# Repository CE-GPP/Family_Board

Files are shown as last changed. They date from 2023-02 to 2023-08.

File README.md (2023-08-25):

# by Team 4 for CASA0021

- Leo Liu : ucfniup@ucl.ac.uk

- Sophia Chong : sophia.chong.19@ucl.ac.uk
- Xiaoya Nie : ucfnnie@ucl.ac.uk

We built the family board project. If you have any questions, please contact us.

# Family Board

Project introduction:

Family board is a device that can allow family members to upload and share their location with family members. It has a physical device and its digital twin on the Android Unity Mobile Application. All the location information is self-reported. It does not have privacy issues (like personal location tracking). This device has a warm, home-like appearance.

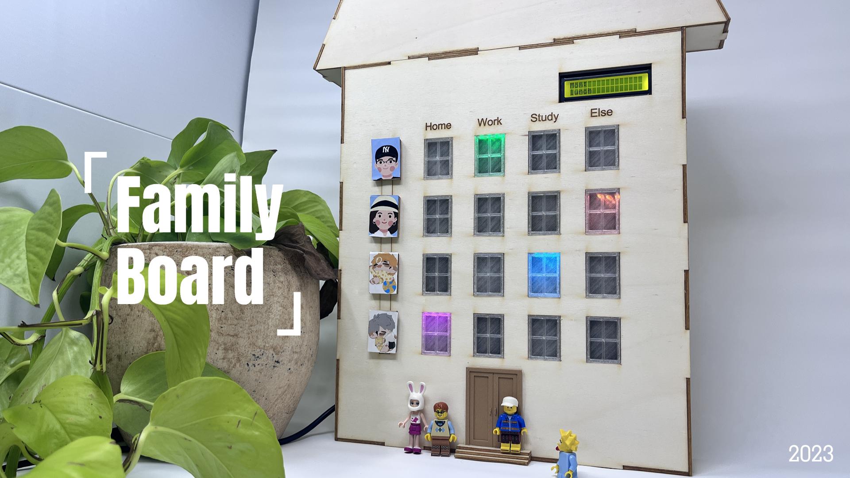
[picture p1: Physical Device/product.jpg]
 - 

To use the physical device, user just need to tap their unique PFID tag on the "door", the window light on the device will change.
User can also change location in app. When they are at other location, they can input message in the pannel. The physical device will show the message on the LCD screen.

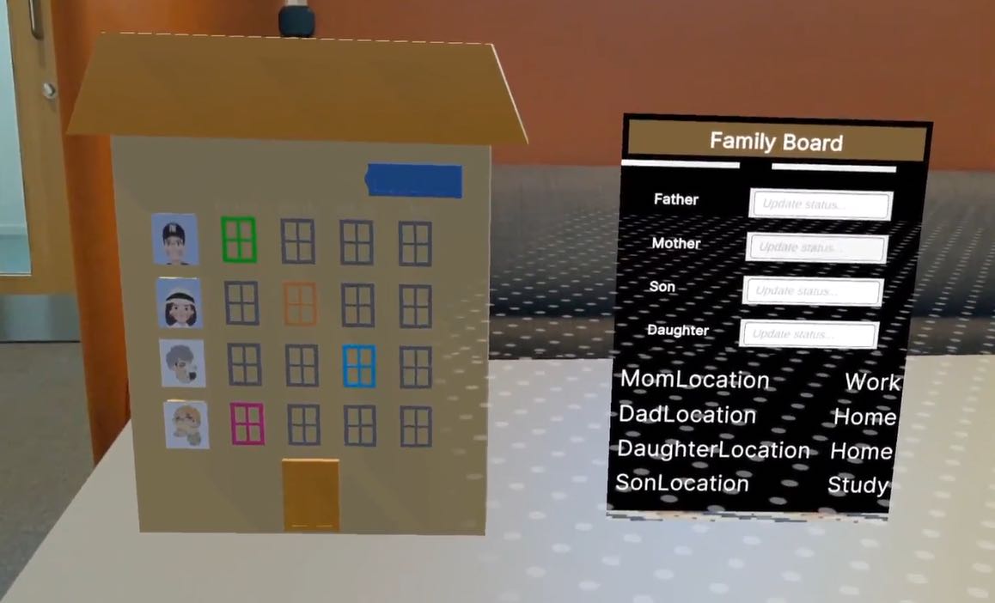
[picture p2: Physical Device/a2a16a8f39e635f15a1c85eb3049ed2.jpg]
 - 

# Getting Started

## Physical Device:

### 1. Hardware required:

The hardware required for the project are:

1). Adafruit Feather HUZZAH ESP8266 

2). MRCF522 RFID module

3). WS2812b led strip: to make the led strip fit with the family board, it need to be cut in to 4 pieces, and solder with cable to rebuild the circuit connection.

4). LCD (I2C)

The function of the hardware can be found below:

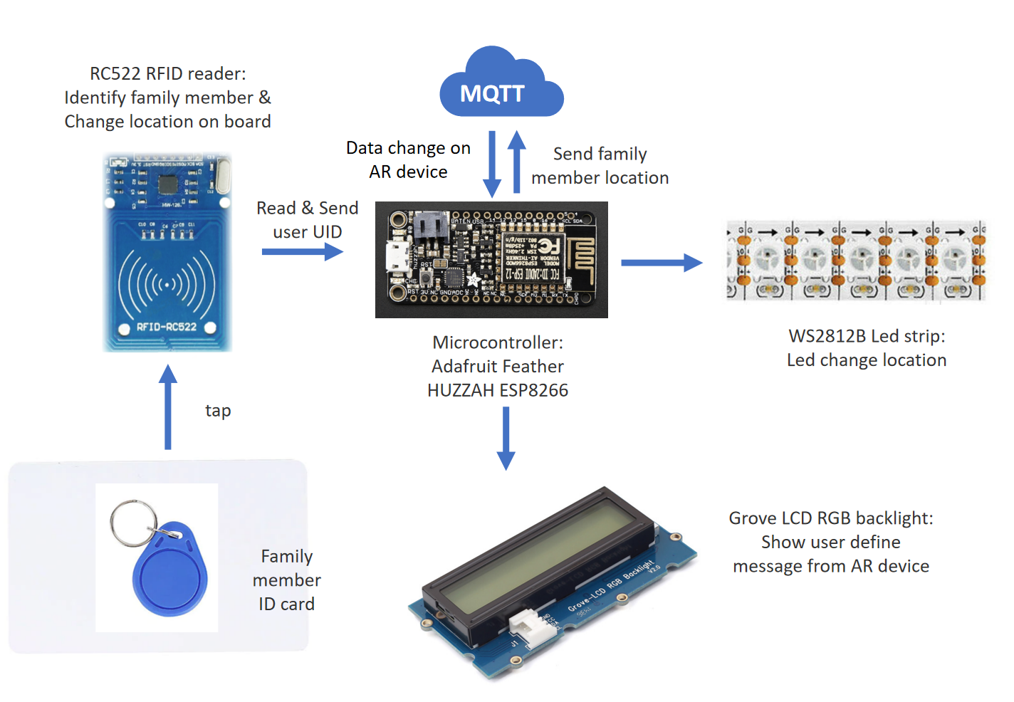
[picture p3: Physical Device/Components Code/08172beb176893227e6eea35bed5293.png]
 - 
 
### 2. Hardware code:

The code for the hardware is in the Physical device folder: CardLCD.ino.
The platform used for the project is Arduino IDE. Please download the code and upload it to the microcontroller.
The circuit connection for the RFID module can also be found in the code.

## 3. Physical Model and Assembly
You will need:
1. 3mm plywood
2. All the leftover plywood scraps from laser cutting
3. Access to a laser cutter
4. Access to a 3D printer
5. Access to a printer
6. Paper
7. Portraits of 4 family members
8. Transparent PLA filament
9. Wood PLA filament
10. Wood glue
11. Tape
12. Multipurpose adhesive
13. Fine grain sandpaper
14. 1 piece of black paper
15. A magnetic sheet
16. Scissors
17. Ruler
18. Cable ties

## 3.1 3D printing
Download the files in the [3D printed components folder](https://github.com/CE-GPP/Family_Board/tree/main/Physical%20Device/3D%20printed%20components) in the Physical Device folder. 
Upload both gcode files to the SD card of a 3D printer, and print the familyBoardDoor with 0.2mm wood PLA filament.
Next, print the twoFamilyBoardWindows with 0.2mm transparent PLA filament, and **repeat this 8 times** to print all 16 windows you need. 
Next, print the familyBoardLCDScreenHolder with 0.2mm PLA filament of your choice.

## 3.2 Laser cutting
Download both files in the [Laser cut template folder](https://github.com/CE-GPP/Family_Board/tree/main/Physical%20Device/Laser%20cut%20template) in the Physical Device folder.

### 3.2.1 Laser cutting the family board face
After opening the familyBoardFace file and exporting it to the laser cutter, set the **location labels** and **spaces for the magnetic family portraits**, which are the **first columnn of rectangles from the left** to **engrave** instead of **cut**. All other lines can be set to **cut**. 
After making this change, it can be laser cut onto 3mm plywood.

### 3.2.2 Laser cutting the family board roof
After opening the familyBoardRoof file and exporting it to the laser cutter, ensure that all its lines are set to **cut**. It can then be laser cut onto 3mm plywood.

## 3.3 Assembling the family board
After you have laser cut the family board face, **keep the leftover plywood scraps** as you need them for later.

### 3.3.1 Assembling the family board face
Assemble the exterior faces of the board with wood glue one by one, and tape each of glued edges together for a secure finish. In the process, ensure that all the components are orientated correctly, and check that the slots at the side of the board are close to the board's front instead of the board's back. 

Next, glue the two walls without finger joints to the top and bottom of the board's interior. Ensure that it is glued as tightly as possible, as this is going to form the rail for the sliding face.

Glue the top of the rails to the back of the top and bottom faces of the board, and glue the grip rail to the sliding face.

Very carefully slot the sliding face of the board into the rail created for it, with the raised edge of the grip rail facing outwards, and check whether it is able to slide in smoothly or not.If not, then remove the debris inside the rail or sand down the wood edges for smoother motion.


Tape or glue the piece of black paper to the back of sliding face, in the area that will be behind the windows when the board is closed. This will prevent excessive light reflection between each window from the LED strip.


Glue the support beams into the sides of the board, with the side with the hole closer to the end of the beam on the left side (the side of the LCD screen) of the board.

Glue the stair pieces to each other, then glue it underneath the hole for the door in the front of the board, so that the hole for the door is positioned above the middle of the stairs, about 10mm away from each end.

After following these steps, you should have a completely assembled the laser cut components of your family board face. Leave the board to dry for at least 2 hours.
 
### 3.3.2 Assembling the family board roof
Assemble each face of the roof with wood glue one by one, and tape each of the glued edges together for a secure finish. It should look like this:


Leave the roof to dry for at least 2 hours.

Then you can glue the longer base of the roof to the top of the family board, leaving about 35mm of overhang on each side.


## 3.4 Adding 3D printed and electronic components

### 3.4.1 Adding the 3D printed components
Slot each of the 3D printed windows into the 4 rows of rectangular holes on the board. In this process, you will have to slightly sand down the edges of each window and the holes in the board to make them fit snugly without adhesive. 

Next, glue the 3D printed door to the front of the board on top of the stairs with multipurpose adhesive, covering the hole.

The board should now look like this:


Slot the LCD screen into the 3D printed LCD screen holder, and position it on top of the top inner support beam so the LCD screen is aligned with and visible from the hole cut for it in the front of the board. To do so, you may need to place a scrap piece of plywood underneath the LCD screen holder to prop it up so the screen can be fully visible through the hole. 


Then take out the LCD screen to wire it, and glue the LCD screen holder into the suitable position with multipurpose adhesive.

### 3.4.2 Adding electronic components
Wire the electronic components of the device. 

Thread the LED strip through each of the support beams and position them on underside of each one. To ensure the correct positioning of each LED pixel in accordance with our code, each of the 4 LED strips should always be placed from **right(side close to the family portraits magnets)** to **left (side close to the LCD screen)**. The spacing should be accurate if you position **the first 4 LED pixels** on each separate LED strip **behind the window the far right (side close to the family portait magnets)** in each row. Afterwards, peel the sticker off the LED strip and stick them in the correct position, and further secure it with cable ties.


Slot the wired LCD screen into the now-secured LCD screen holder. 


Position the RFID reader horizontally in the space behind the 3D printed door. 
Place 2 leftover plywood scraps perpendicular to each other and glue them to the bottom of the board near the corner of the RFID reader to secure it in place behind the door.  


### 3.4.3 Adding the family portrait magnets
To create the family portrait magnets, print the portraits of four of your family members on paper around 36mm tall and 26mm wide and cut them out.
Cut 8 rectangles of that same length and width (36mm x 26mm) out of your magnetic sheet. Glue 4 of them in the engraved rectangles on the face of the family board with multipurpose adhesive to make the magnetic surface to attach the family portrait magnets to. 
Glue your printed family portraits to the remaining 4 magnetic sheets, and stick them onto the 4 magnetic surfaces of the board.

After following these steps, the physical family board should be ready for use!



## Virtual Device:

### 1. Download The Virtual Device Android APP from Unity

1. Head over to the [Family Board Virtual Device folder](https://github.com/CE-GPP/Family_Board/tree/main/Unity/Family%20Board%20Virtual%20Device) and open the folder as a new project in Unity. Before you begin, make sure that your project is set up in Unity 2021.3.13f1. The Mobile application for Family Board only supports the Android platform.

2. In Unity, open the Prefab folder and double-click the "Final model" file to open it. In the Hierarchy window on the left, click the UI layer under "Final model" once. Then, enter your MQTT user name and password under "Mqtt Receiver List (Script)" in the Inspector window on the right. Feel free to change the MQTT broker address and use your own MQTT server instead of the CE MQTT server. Save your project to prepare for building the app in the next step.

3. From the top menu bar, select File and go to Build Settings. Select Android from the right platform lists and click Build and Run. Then, save the project in the desired location and make sure the Android mobile device is connected to Unity through a USB cable. Do not disconnect the mobile device until the Unity app automatically starts on the device.

### 2. The Virtual Device Android APP

The goal of the Android app developed using Unity is to allow users to check or manipulate their family boards remotely through their mobile devices. The app contains a digital twin of the physical device and a user interface panel.

The virtual device has the same functions and appearance as the physical device, and the model was imported into Unity from Fusion 360 directly. Both physical and virtual devices are connected through MQTT. However, the LCD is not responsive on the virtual device because the UI panel beside it can display more information in a clear and organized way. The virtual device is interactable since users can change their status by clicking on the windows. We kept the buttons transparent for better user experiences. 

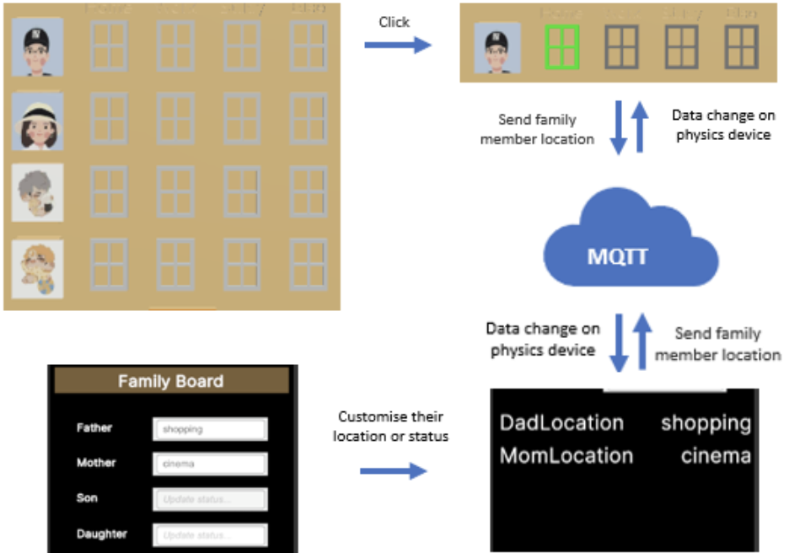
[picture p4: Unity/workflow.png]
- 
- AR application workflow.

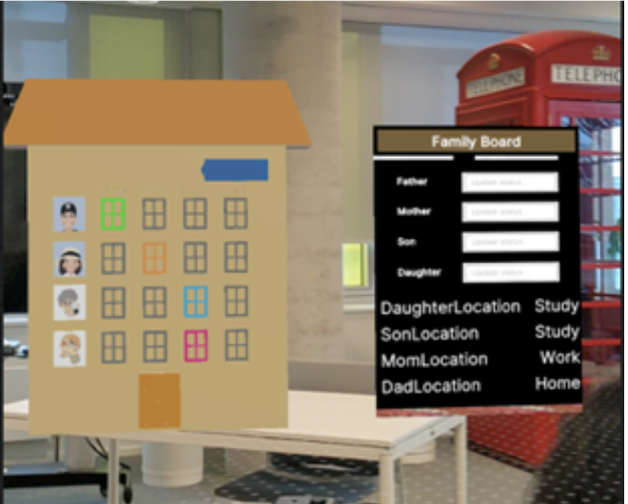
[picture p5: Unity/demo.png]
- 
- The final version of the Virtual device and the Android app.

# Contributing

This project welcomes contributions and suggestions.  Most contributions require you to agree to a
Contributor License Agreement (CLA) declaring that you have the right to, and actually do, grant us
the rights to use your contribution. For details, visit https://cla.microsoft.com.

When you submit a pull request, a CLA-bot will automatically determine whether you need to provide
a CLA and decorate the PR appropriately (e.g., label, comment). Simply follow the instructions
provided by the bot. You will only need to do this once across all repos using our CLA.

This project has adopted the [Microsoft Open Source Code of Conduct](https://opensource.microsoft.com/codeofconduct/).
For more information see the [Code of Conduct FAQ](https://opensource.microsoft.com/codeofconduct/faq/) or
contact [opencode@microsoft.com](mailto:opencode@microsoft.com) with any additional questions or comments.

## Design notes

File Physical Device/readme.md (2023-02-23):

## Physical device

### The design and code for physical device

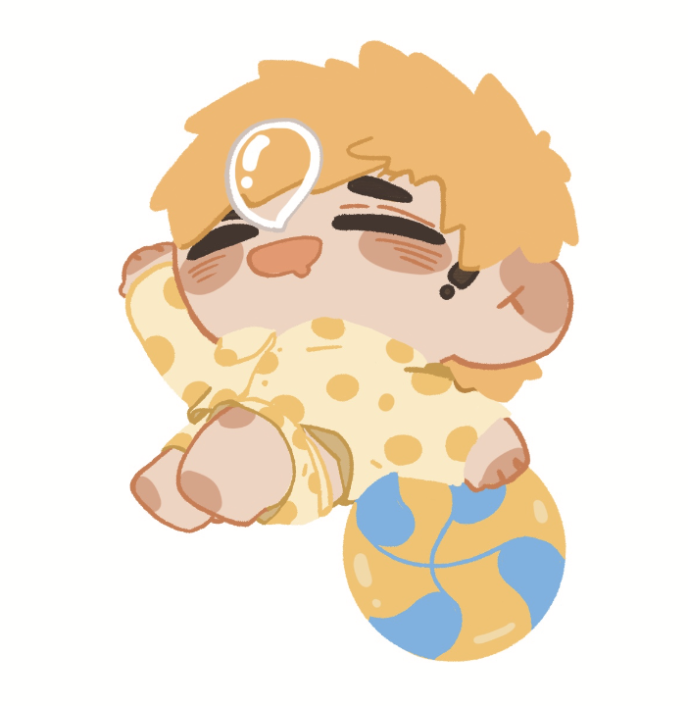
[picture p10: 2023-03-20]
Unity/Family Board Virtual Device/Assets/Prefab/Daughter.jpg

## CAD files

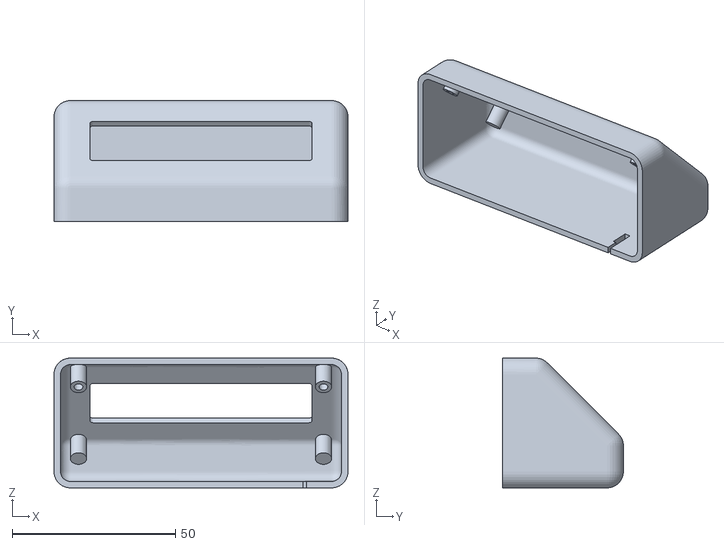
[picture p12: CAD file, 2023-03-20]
Fusion 360/lcd_housing.STL
90.0 x 37.0 x 39.7

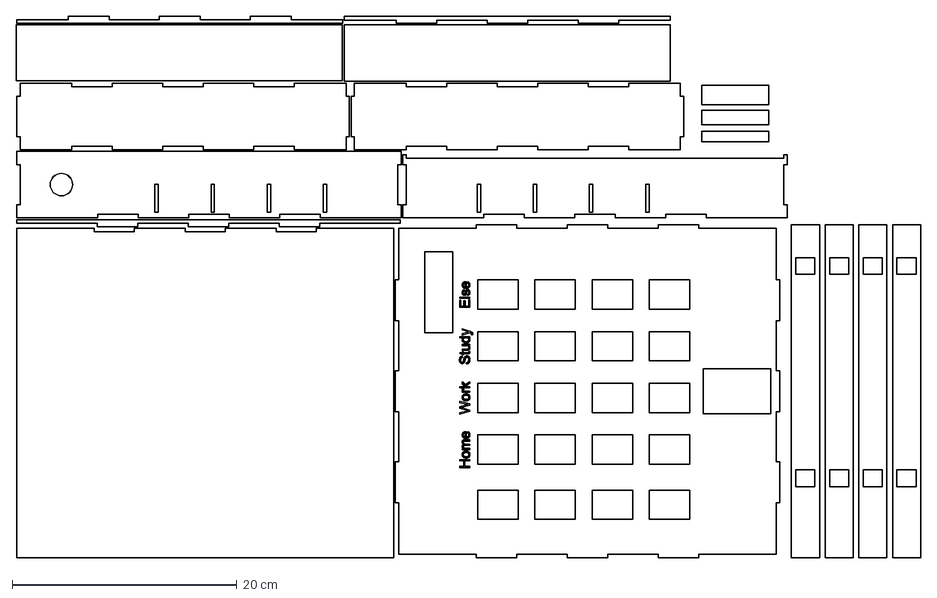
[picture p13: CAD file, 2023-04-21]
Physical Device/Laser cut template/familyBoardFace.dxf
80.5 x 48.2 cm

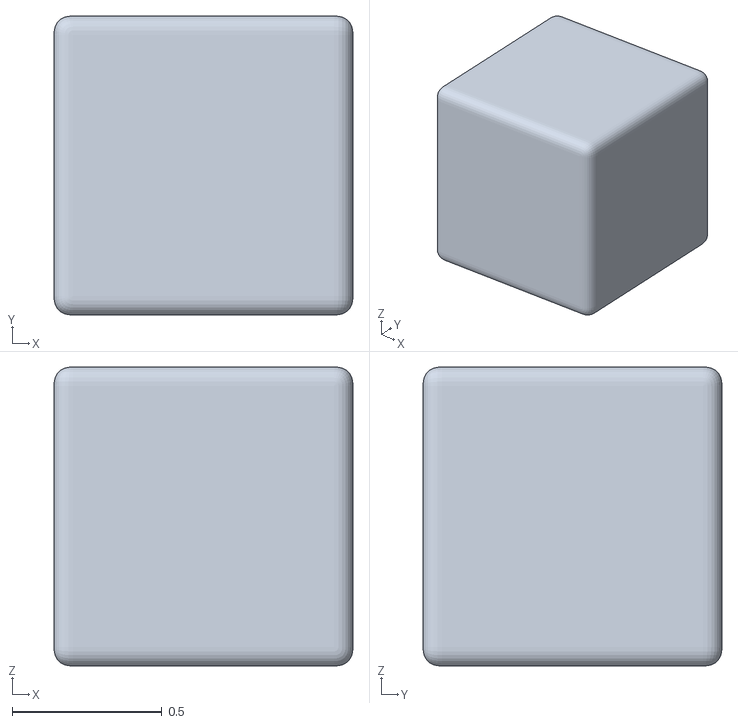
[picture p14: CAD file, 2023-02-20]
Unity/Family Board Virtual Device/Assets/Plugins/CW/LeanCommon/Examples/Meshes/RoundedCube.obj
1.00 x 1.00 x 1.00

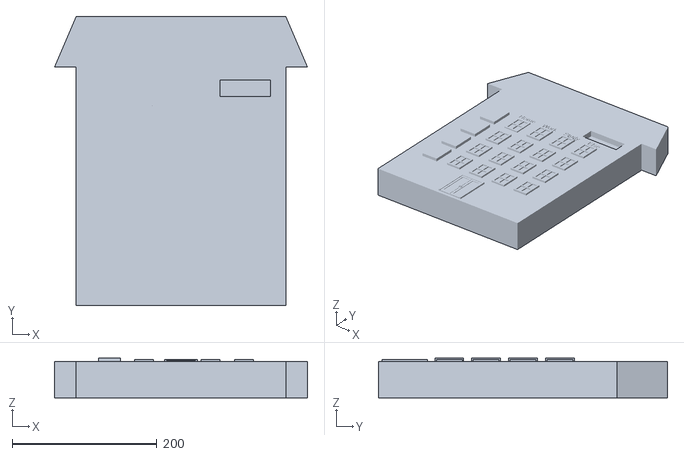
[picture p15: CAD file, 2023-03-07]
Unity/Family Board Virtual Device/Assets/Prefab/familyBoardSTL.stl
350.0 x 400.0 x 55.0

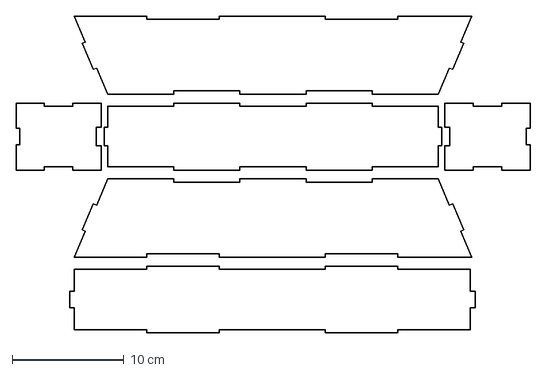
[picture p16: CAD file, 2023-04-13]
Physical Device/Laser cut template/familyBoardRoof.dxf
46.1 x 28.4 cm

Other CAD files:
Unity/familyBoardOBJ.obj
Fusion 360/boardDoor.f3d
Fusion 360/boardRoof.f3d
Fusion 360/boardWindow.f3d
Fusion 360/familyBoardTemplate.f3d
Fusion 360/status_board_vertical_v9.f3d
Unity/Family Board Virtual Device/Assets/Prefab/s_board_vertical_v9_v159_v15.f3z

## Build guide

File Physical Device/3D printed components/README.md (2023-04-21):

3D printed components of our familly board

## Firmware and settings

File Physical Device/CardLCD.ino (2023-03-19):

/*
 * Family Board - Physical device 
 *
 * Uses MIFARE RFID card using RFID-RC522 reader
 * Uses MFRC522 - Library
 * -----------------------------------------------------------------------------------------
 *             MFRC522      Arduino      
 *             Reader/PCD   Feather Huzzah 
 * Signal      Pin          Pin          
 * -----------------------------------------------------------------------------------------
 * RST/Reset   RST          0           
 * SPI SS      SDA(SS)      15            
 * SPI MOSI    MOSI         13
 * SPI MISO    MISO         12
 * SPI SCK     SCK          14
*/

//library used in the project, for LCD RFID Reader, Wifi MQTT
#include <SPI.h>
#include <MFRC522.h>
#include <ESP8266WiFi.h>
#include <ESP8266WebServer.h>
#include <ezTime.h>
#include <PubSubClient.h>
#include <FastLED.h>
#include <Wire.h>
#include <LiquidCrystal_I2C.h>

//pin define
#define LED_PIN     16
#define NUM_LEDS    96

//LED strip brightness
int brightness = 50; 

CRGB leds[NUM_LEDS];
 
#define SS_PIN 15
#define RST_PIN 0

MFRC522 rfid(SS_PIN, RST_PIN); 
 
// initialize array to store NUID that has been read
byte nuidPICC[4];
const int numOfCards = 4;//the nuber of cards. this can change as you want
byte cards[numOfCards][4] = {{0xC3, 0x08, 0x30, 0x95},{0x73, 0x25, 0x3F, 0x92},{0x73, 0x25, 0x3F, 0x93},{0x73, 0x25, 0x3F, 0x94}}; // array of UIDs of rfid cards
int n = 0;//n is for the total number of family members
//j is for to detect the card is valid or not
int numCard[numOfCards]; //this array content the details of cards that already detect or not .
String names[numOfCards] = {"Dad","Mom","Daughter","Son"};//each family member
//1-Home,2-Study,3-Work,4-Else;
int fLocations[numOfCards] = {1,1,1,1};//family member locations


// Wifi and MQTT
#include "arduino_secrets.h" 

//sensitive data saved in arduino secret file
const char* ssid     = SECRET_SSID;
const char* password = SECRET_PASS;
const char* mqttuser = SECRET_MQTTUSER;
const char* mqttpass = SECRET_MQTTPASS;

//MQTT and WiFi connection
ESP8266WebServer server(80);
const char* mqtt_server = "mqtt.cetools.org";
WiFiClient espClient;
PubSubClient client(espClient);
long lastMsg = 0;
char msg[50];
int value = 0;

// Date and time
Timezone GB;

//LCD Display
int totalColumns = 16;
int totalRows = 2;
//I2C pins declaration for 1602A with I2C module
LiquidCrystal_I2C lcd(0x27, totalColumns, totalRows);

void setup() { 
  Serial.begin(9600);
  SPI.begin(); // initialize SPI
  rfid.PCD_Init(); // initialize MFRC522 

    // run initialisation functions
  startWifi();
  syncDate();

  FastLED.addLeds<WS2812, LED_PIN, GRB>(leds, NUM_LEDS);
  FastLED.setBrightness(brightness);

  // start MQTT server
  client.setServer(mqtt_server, 1884);
  client.setCallback(callback);

  // set up the LCD's number of columns and rows:
   lcd.init();
   lcd.backlight();  // use to turn on and turn off LCD back light

}
 
void loop() {
  //verify MQTT connection
  if (!client.connected()) {
    reconnect();
  }
  client.loop();
 
  // find card
  if ( ! rfid.PICC_IsNewCardPresent())
    return;
 
  // verify if NUID is readable
  if ( ! rfid.PICC_ReadCardSerial())
    return;
  int j = -1;
  MFRC522::PICC_Type piccType = rfid.PICC_GetType(rfid.uid.sak);
 
  // Check whether the card type is MIFARE
  if (piccType != MFRC522::PICC_TYPE_MIFARE_MINI &&  
    piccType != MFRC522::PICC_TYPE_MIFARE_1K &&
    piccType != MFRC522::PICC_TYPE_MIFARE_4K) {
    Serial.println("Type not support");
    return;
  }
  
  // Save the NUID to the nuidPICC array
  for (byte i = 0; i < 4; i++) {
    nuidPICC[i] = rfid.uid.uidByte[i];
  }   

  for (int i = 0; i < numOfCards; i++) {
    if (nuidPICC[0] == cards[i][0] && nuidPICC[1] == cards[i][1] && nuidPICC[2] == cards[i][2] && nuidPICC[3] == cards[i][3]) {
      j = i;
    }
  }
  if(j == -1) {//check the card validity
    invalid();
  }
  else {
    //send data to display and save
    logCardData(names[j], fLocations[j], j);
    sendMQTT();
  }

  
  // set IC card placed in the reading area enters hibernation state, no longer read the card repeatedly
  rfid.PICC_HaltA();
 
  // Stop reading the card module code
  rfid.PCD_StopCrypto1();

}
//function for invalid information
void invalid(){
  Serial.println("Invalid Card.");
  lcd.clear();
  // Print a message to the LCD.
  lcd.setCursor(0, 0);
  lcd.print("Card not defined");
}

//function for Change family member location
void logCardData(String name, long fLocation, int j){
  //change card location
  fLocations[j] = fLocations[j] + 1;
  if (fLocations[j]==5)
  {
    fLocations[j]=1;
  }
  numCard[j] = 1;//put 1 in the numCard array : numCard[j]={1,1} to let the arduino know if the card was detecting

  //display details to the console (serial monitor)
  Serial.print("Family member: ");
  Serial.println(name); //print name of family member
  Serial.print("Location: ");
  Serial.println(fLocation); //print location of member
  Serial.println();
  showLED();
  FastLED.show();

}

//function for change led strip light
void showLED(){
  Serial.println("change light");
  FastLED.clearData();
  //dad location
  switch (fLocations[0]) {
    case 1:  // home
    for (int i = 72; i <= 75; i++) {
    leds[i] = CRGB (0, 0, 255);
    }
      break;
    case 2:  // study
    for (int i = 79; i <= 82; i++) {
    leds[i] = CRGB ( 0, 0, 255);
    }
      break;
    case 3:  // work
    for (int i = 86; i <= 89; i++) {
    leds[i] = CRGB ( 0, 0, 255);
    }  
      break;
    case 4:  // else
    for (int i = 93; i <= 95; i++) {
    leds[i] = CRGB ( 0, 0, 255); 
    }
      break;
  }
 // FastLED.show();
  //mom location
  switch (fLocations[1]) {
    case 1:  // home
    for (int i = 48; i <= 51; i++) {
    leds[i] = CRGB ( 204, 85, 0); 
    }
      break;
    case 2:  // study
    for (int i = 55; i <= 58; i++) {
    leds[i] = CRGB ( 204, 85, 0);
    }
      break;
    case 3:  // work
    for (int i = 62; i <= 65; i++) {
    leds[i] = CRGB (204, 85, 0);
    }  
      break;
    case 4:  // else
    for (int i = 69; i <= 71; i++) {
    leds[i] = CRGB ( 204, 85, 0);
    }
      break;
  }
    FastLED.show();
  //Daugther location
  switch (fLocations[3]) {
    case 1:  // home
    for (int i = 24; i <= 27; i++) {
    leds[i] = CRGB (255,20,147);
    }
      break;
    case 2:  // study
    for (int i = 31; i <= 34; i++) {
    leds[i] = CRGB ( 255,20,147);
    }
      break;
    case 3:  // work
    for (int i = 38; i <= 41; i++) {
    leds[i] = CRGB ( 255,20,147);
    }  
      break;
    case 4:  // else
    for (int i = 45; i <= 47; i++) {
    leds[i] = CRGB ( 255,20,147);
    }
      break;
  }
    FastLED.show();
  //son location
  switch (fLocations[2]) {
    case 1:  // home
    for (int i = 0; i <= 3; i++) {
    leds[i] = CRGB ( 0, 255, 0);
    }
      break;
    case 2:  // study
    for (int i = 7; i <= 10; i++) {
    leds[i] = CRGB ( 0, 255, 0);
    }
      break;
    case 3:  // work
    for (int i = 14; i <= 17; i++) {
    leds[i] = CRGB ( 0, 255, 0);
    }  
      break;
    case 4:  // else
    for (int i = 21; i <= 23; i++) {
    leds[i] = CRGB ( 0, 255, 0);
    }
      break;
  }
    FastLED.show();
}

//Wifi connnection
void startWifi() {
  // We start by connecting to a WiFi network
  Serial.println();
  Serial.print("Connecting to ");
  Serial.println(ssid);
  WiFi.begin(ssid, password);

  // check to see if connected and wait until you are
  while (WiFi.status() != WL_CONNECTED) {
    delay(500);
    Serial.print(".");
  }
  Serial.println("");
  Serial.println("WiFi connected");
  Serial.print("IP address: ");
  Serial.println(WiFi.localIP());
}

void syncDate() {
  // get real date and time
  waitForSync();
  Serial.println("UTC: " + UTC.dateTime());
  GB.setLocation("Europe/London");
  Serial.println("London time: " + GB.dateTime());

}

//send message to MQTT
void sendMQTT() {

  if (!client.connected()) {
    reconnect();
  }
  client.loop();
  int MOML = fLocations[1];
  snprintf (msg, 50, "%.0i", MOML);
  Serial.print("Publish message for mom: ");
  Serial.println(msg);
  client.publish("student/ucfnnie/FamilyBoard/Mom/MomLocation", msg);

 
  snprintf (msg, 50, "%.0i", fLocations[0]);
  Serial.print("Publish message for Dad: ");
  Serial.println(msg);
  client.publish("student/ucfnnie/FamilyBoard/Dad/DadLocation", msg);

  
  snprintf (msg, 50, "%.0i", fLocations[2]);
  Serial.print("Publish message for Daughter: ");
  Serial.println(msg);
  client.publish("student/ucfnnie/FamilyBoard/Daughter/DaughterLocation", msg);

 
  snprintf (msg, 50, "%.0i", fLocations[3]);
  Serial.print("Publish message for Son: ");
  Serial.println(msg);
  client.publish("student/ucfnnie/FamilyBoard/Son/SonLocation", msg);

}

//callback receive function
void callback(char* topic, byte* payload, unsigned int length) {
  Serial.print("Message arrived [");
  Serial.print(topic);
  Serial.print("] ");
  for (int i = 0; i < length; i++) {
    Serial.print((char)payload[i]);
  }
  Serial.println();
  char str[length+1];
  if(strcmp(topic,"student/ucfnnie/FamilyBoard/Dad/DadLocation")==0 ){
    payload[length] = '\0'; // Add a NULL to the end of the char* to make it a string.
    int aNumber = atoi((char *)payload);
    fLocations[0] = aNumber;
  }
   if(strcmp(topic,"student/ucfnnie/FamilyBoard/Mom/MomLocation")==0 ){
    payload[length] = '\0'; // Add a NULL to the end of the char* to make it a string.
    int aNumber = atoi((char *)payload);
    fLocations[1] = aNumber;
  }
   if(strcmp(topic,"student/ucfnnie/FamilyBoard/Daughter/DaughterLocation")==0 ){
    payload[length] = '\0'; // Add a NULL to the end of the char* to make it a string.
    int aNumber = atoi((char *)payload);
    fLocations[2] = aNumber;
  }
   if(strcmp(topic,"student/ucfnnie/FamilyBoard/Son/SonLocation")==0 ){
    payload[length] = '\0'; // Add a NULL to the end of the char* to make it a string.
    int aNumber = atoi((char *)payload);
    fLocations[3] = aNumber;
  }
    if(strcmp(topic,"student/ucfnnie/FamilyBoard/Dad/DadElse")==0 ){
    for (int i = 0; i < length; i++) {
      // Serial.print((char)payload[i]);
      str[i] = (char)payload[i];
      lcd.clear();
      // Print a message to the LCD.
       // (note: line 1 is the second row, since counting begins with 0):
      lcd.setCursor(0, 0);
      lcd.print("Dad:");
    }
  }
   if(strcmp(topic,"student/ucfnnie/FamilyBoard/Daughter/DaughterElse")==0 ){
    for (int i = 0; i < length; i++) {
      // Serial.print((char)payload[i]);
      str[i] = (char)payload[i];
      lcd.clear();
      // Print a message to the LCD.
       // (note: line 1 is the second row, since counting begins with 0):
      lcd.setCursor(0, 0);
      lcd.print("Daughter:");
    }
  }
   if(strcmp(topic,"student/ucfnnie/FamilyBoard/Son/SonElse")==0 ){
    for (int i = 0; i < length; i++) {
      // Serial.print((char)payload[i]);
      str[i] = (char)payload[i];
      lcd.clear();
      // Print a message to the LCD.
       // (note: line 1 is the second row, since counting begins with 0):
      lcd.setCursor(0, 0);
      lcd.print("Son:");
    }
  }
   if(strcmp(topic,"student/ucfnnie/FamilyBoard/Mom/MomElse")==0 ){
    for (int i = 0; i < length; i++) {
      // Serial.print((char)payload[i]);
      str[i] = (char)payload[i];
      lcd.clear();
      // Print a message to the LCD.
       // (note: line 1 is the second row, since counting begins with 0):
      lcd.setCursor(0, 0);
      lcd.print("Mom:");
    }
  }
  showLED();
  FastLED.show();
   lcd.setCursor(0, 1);
  lcd.print(str);
}

//reconnect to MQTT
void reconnect() {
  // Loop until we're reconnected
  while (!client.connected()) {
    Serial.print("Attempting MQTT connection...");
    // Create a random client ID
    String clientId = "ESP8266Client-";
    clientId += String(random(0xffff), HEX);
    
    // Attempt to connect with clientID, username and password
    if (client.connect(clientId.c_str(), mqttuser, mqttpass)) {
      Serial.println("connected");
      // ... and resubscribe
      client.subscribe("student/ucfnnie/FamilyBoard/Dad/DadLocation");
      client.subscribe("student/ucfnnie/FamilyBoard/Dad/DadElse");
      client.subscribe("student/ucfnnie/FamilyBoard/Mom/MomLocation");
      client.subscribe("student/ucfnnie/FamilyBoard/Mom/MomElse");
      client.subscribe("student/ucfnnie/FamilyBoard/Daughter/DaughterLocation");
      client.subscribe("student/ucfnnie/FamilyBoard/Daughter/DaughterElse");
      client.subscribe("student/ucfnnie/FamilyBoard/Son/SonLocation");
      client.subscribe("student/ucfnnie/FamilyBoard/Son/SonElse");
    } else {
      Serial.print("failed, rc=");
      Serial.print(client.state());
      Serial.println(" try again in 5 seconds");
      // Wait 5 seconds before retrying
      delay(5000);
    }
  }
}

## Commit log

2023-02-21 Add files via upload
    windows on our family board
    [window thin v1.f3d]
2023-02-24 Update read_RFID.ino
    change the board from uno to huzzah
2023-03-04 Laser cut design file of our board
    Made in Fusion360, laser cut on 3mm plywood
    [Familyboard.f3d]
2023-03-07 update model
    [familyBoardOBJ.obj, familyBoardSTL.stl, s_board_vertical_v9_v159_v15.f3z]
2023-03-14 Add files via upload
    Laser cut template for the roof of our board
    [boardRoof.f3d]
2023-03-14 Add files via upload
    Fusion360 model of the windows we 3D printed with transparent PLA filament for our board
    [boardWindow.f3d]
2023-03-14 board door
    Fusion360 model of the board door which we 3D printed with wood PLA filament
    [boardDoor.f3d]
2023-03-14 board roof
    Laser cut template for the roof of the board made with 3mm plywood
    [boardRoof.dxf, boardRoof.f3d]
2023-03-14 board window
    Fusion360 model of window we 3D printed with transparent PLA filament
    [boardWindow.f3d]
2023-03-14 3D object of our board
    3D game object of our board, modelled in Fusion360 then exported to Unity
    [familyBoardOBJ.obj]
2023-03-15 CodeChangeLED
    add code to change location with led
2023-03-19 Upload code for physical device
2023-03-20 final version
    [lcd_housing.STL]
2023-03-21 Family Board laser cut template
    Laser cut template of our family board, printed on 3mm plywood
    [familyBoardTemplate.f3d]
2023-03-24 Create readme.md
    DXF files of the components of the family board (board faces, roof, stairs, inner supports) that can be laser cut onto 3mm plywood
2023-03-24 Family board face
    Contains the laser cut template of the faces of the family board, inner supports for LED strips, and stairs for the door, meant to be laser cut onto 3mm plywood. The board is a box with a sliding bac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
    [familyBoardFace.dxf]
2023-03-24 Laser cut template of family board roof
    Laser cut template of the roof of the family board, suitable for laser cutting onto 3mm plywood. After assembly, one should glue it to the top of the family board leaving a 30mm overhang on each side.
    [familyBoardRoof.dxf]
2023-04-13 Board roof
    File of the faces of the family board's roof, made with Jerome Leary's Box Generator and further modified on Fusion360
    [boardRoof.f3d]
2023-04-13 Laser cut template of the family board's roof
    Laser cut template of the family board's roof, meant to be cut on 3mm plywood
    [familyBoardRoof.dxf]
2023-04-19 final project
    [lcd_housing.STL]
2023-04-21 Family Board Door
    Gcode to 3D print the door of our family board, that should be printed with 0.20mm wood PLA filament
2023-04-21 3D print of family board windows
    Gcode for 3D printing the windows of our family board: this file contains 2 windows
2023-04-21 Family board face
    Laser cut template for the face of the family board, suitable for printing on 3mm plywood
    [familyBoardFace.dxf]
2023-04-21 family board LCD screen holder
    Gcode for the LCD screen holder in our family board, meant to be printed with 0.2mm PLA filament
